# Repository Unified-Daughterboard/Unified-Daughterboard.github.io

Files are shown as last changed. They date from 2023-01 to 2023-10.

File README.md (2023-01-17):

# Unified Daughterboard

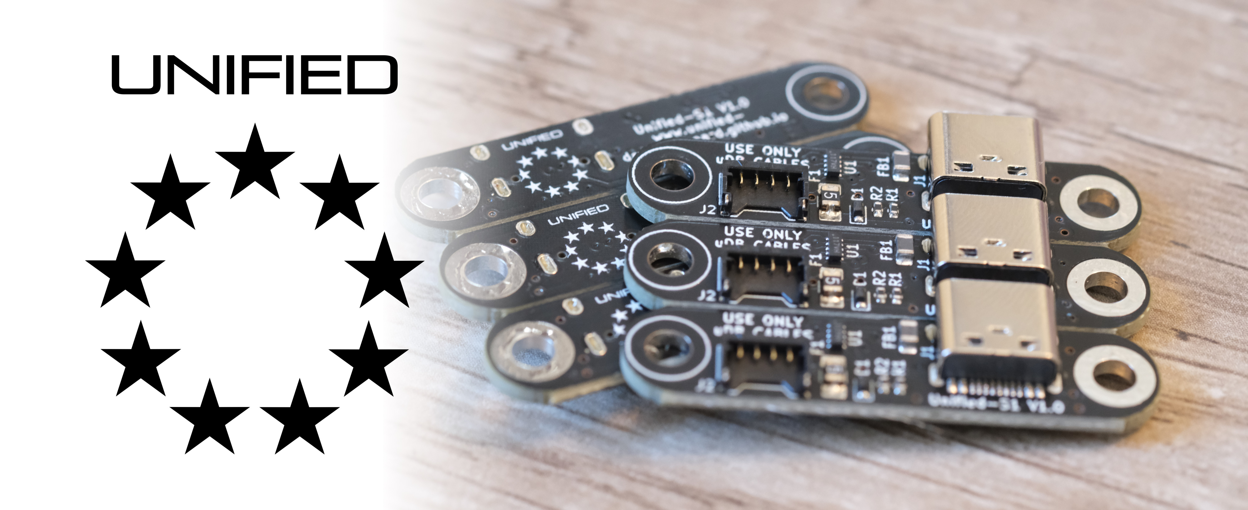
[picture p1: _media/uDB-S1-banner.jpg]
Banner


## Introduction
The Unified Daughterboard Project is an open standard to unify the USB daughterboards used in custom mechanical keyboard projects.  
The USB-to-internal-cable daughterboards allows designers to easily implement electrical protection via a tested proven PCB, and allows users to maintain and repair their keyboards in the future via an open-source standard.  
  
The Unified Daughterboard integrates USB Type C connector and the needed circuitry for USB2.0 operation in a small PCB that can be screwed into a keyboard chassis; this allows for greater case design freedom and simplifies the main circuit board.

## Features
In its latest versions, the daughterboards of this project features ESD protection, overcurrent protection, overvoltage protection, shielding noise decoupling, and single-path grounding to chassis functionality.  
Adittionally, same-letter series (C1, C2, C3, etc.) are backwards compatible, allowing for upgrading daughterboards used in past projects to newer revisions.  

## Project Details
[Roadmap](roadmap.md)  
[Announcements](announcements.md)  

## Resources

[For consumers](info-consumer.md)  
[For case designers](info-designer-case.md)  
[For PCB designers](info-designer-pcb.md)  
[For vendors](info-vendor.md)  
  
[Daughterboard spec and resources](db-spec-list.md)

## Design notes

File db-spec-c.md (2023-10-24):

# C series (C4 and newer) 
Current latest version: C5.0 (Released 2023-10-22)

## Overview

The C series daughterboard is the current most recent revision to the classic square form-factor daughterboard, with its roots in the C1 which was designed to be compatible with Wilba's keyboards.  
The daughterboard features the following:  

* ESD protection, overcurrent protection, overvoltage protection, shielding noise decoupling, and single-path grounding to chassis functionality
* Two variants: The new Molex Pico-EZmate and the classic JST-SH
* 1:1 connector pinout to retain compatibility with existing PCBs
* Same form factor as C1 and C2, allowing for daughterboard upgrades

## Specification

* Overall size: 18 x 16.5 mm
* Screw holes: 14 x 12.5 mm apart.  
* Corner radius: 2 mm
* Hardware: M2 screws
* Connector: Molex Pico-EZmate (781710004)
* PCB layers: 4 (7628 stackup)

## Resources

GitHub: [EZM (Pico-EZmate Variant)](https://github.com/Unified-Daughterboard/UDB-C-EZM ':ignore'), [JSH (JST-SH Variant)](https://github.com/Unified-Daughterboard/UDB-C-JSH ':ignore')  
3D model: [EZM (Pico-EZmate Variant)](/_media/uDB-C4-3D-model.STEP ':ignore'), [JSH (JST-SH Variant)](/_media/uDB-C3-3D-model.STEP ':ignore')  
[Example implementation](/_media/uDB-C4-implementation-example.step ':ignore')  
[Production data](https://github.com/Unified-Daughterboard/UDB-C/tree/main/production ':ignore')  

## Images and Diagrams

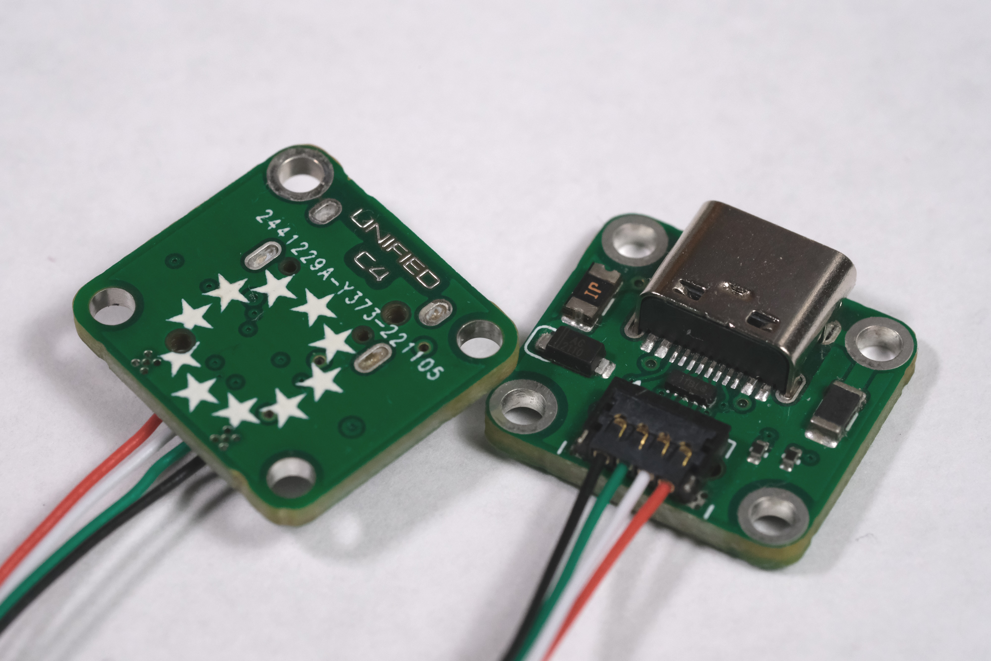
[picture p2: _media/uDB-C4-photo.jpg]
:size=900
  
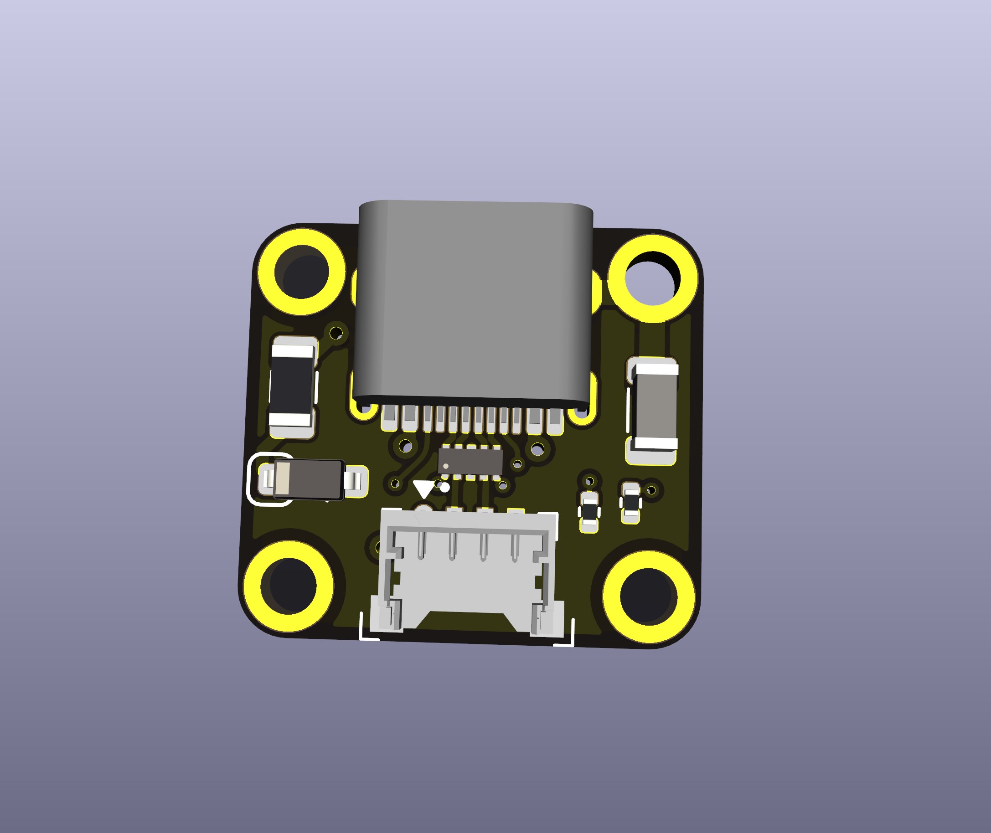
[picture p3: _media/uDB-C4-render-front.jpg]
Render front :size=600
  
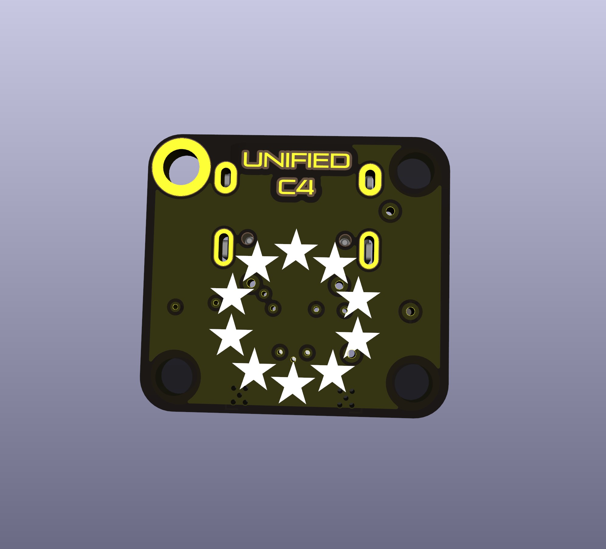
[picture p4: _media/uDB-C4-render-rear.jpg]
Render rear :size=600
  
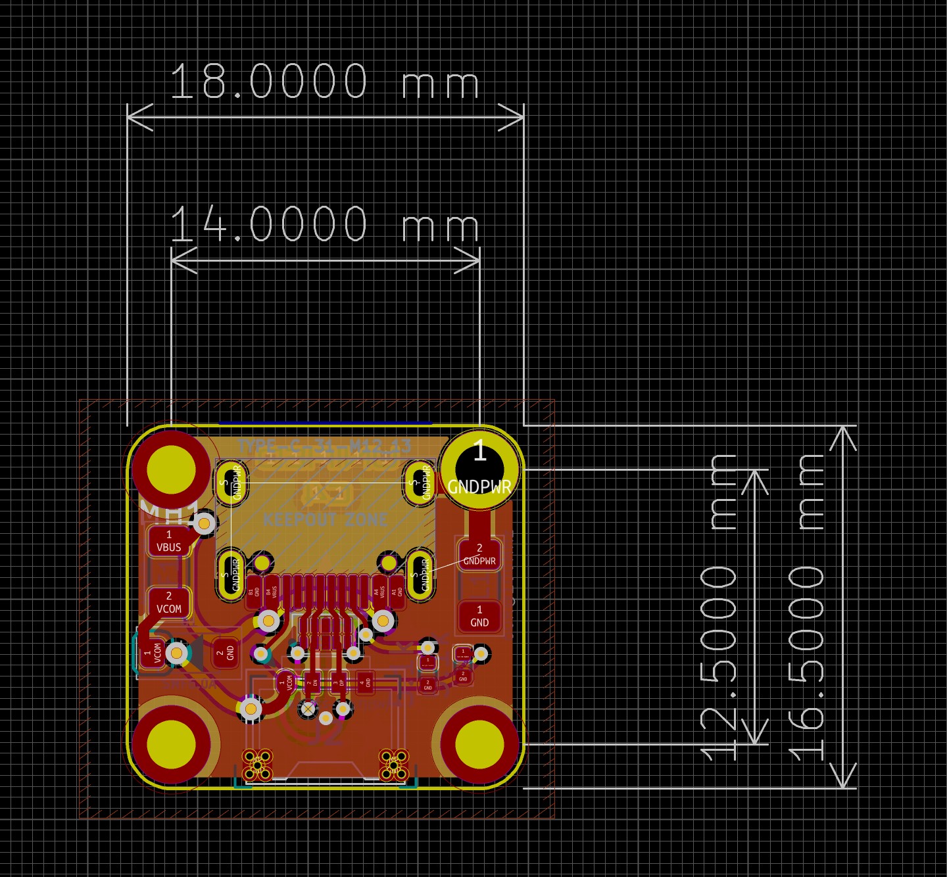
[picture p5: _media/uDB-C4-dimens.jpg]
C :size=600


## Changelog

- 2023-10-22: C5.0 Release
  - Improved ESD handling
  - Added two connector variants
- 2023-03-30: C4.1 Release
  - Updated footprint to S1 series reinforced footprint  
  - Improve USB routing
- 2023-01-18: C4.0 Release
  - Initial release

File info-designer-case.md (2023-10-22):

# Case Designer Info

Information for case designers looking to integrate the Unified Daughterboard into their project.

## Physical dimensions
For dimensions of each daughterboard series, visit [here](db-spec-list.md).  
We recommend importing the provided 3D model for checking dimensional compatibility, as well as checking the example implementations.  
However, please check the important design constraints prior to design.  

## Choosing a daughterboard
We recommend using the newly developed [S series daughterboards](db-spec-s.md) if starting from scratch.  
It is designed to be easier on both the designer and vendor, and has tweaks to reduce possible QC headaches and manufacturing difficulties.  

## Important design constraints
- The PCB should not fully contact the case either on the front or the back - relying on the soldermask to avoid short-circuits against the daughterboard is risky, and has been reported to fail even with no damage to the PCB surface.
  - Instead, air-gap the PCB to the case except for at the screw points. We recommend at least 0.5mm of distance.
- Do not design your keyboard to fit extremely closely against the onboard components - they are subject to change if the circuitry is updated, and the component positions can drift in all directions depending on solder reflow tolerances.
- PCB outline tolerances tend to be around 0.25mm or larger. Please give at least 0.25mm of clearance between the daughterboard design size and surrounding walls.
- Make sure all screws are installed with sufficient thread tap depth.
- Many of the daughterboard's features such as ESD protection rely on a reliable electrical connection from the point of ESD (i.e. the case top half's front bezel) to a select screw point on the daughterboard. Make sure this electrical connection exists through case part contact, screws, and similar if you wish to take advantage of them.

## Cable considerations
A one-to-one 4 pin cable is used to connect the daughterboard to the mainboard - using Pico-EZmate connectors or JST-SH depending on the version.  
  
Consideration should be given to the physical constraints of the cable - for example, make sure it is routed in such a way where it will not be physically damaged during assembly or use.  
A cable too short may interfere with ease of keyboard assembly.  

## Hardware considerations

The C series daughterboards use four M2 screws.  
The S series daughterboards use two M3 screws.  
  
!>The screws should be of regular head type - do not use countersunk screws.  
It is highly recommended to choose a screw with a head diameter lower than 4mm for M2, 6mm for M3. Using larger screws risks the screw reaching over the circuitry-filled areas of the daughterboard.
  
A conductive screw should be used (i.e. uncoated stainless steel) to guarantee conductivity to the case.  
Specifics such as head height and screw length depend on your project's specific constraints.

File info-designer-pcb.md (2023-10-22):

# PCB Designer Info

Information for case designers looking to integrate the Unified Daughterboard into their project.

## Physical dimensions
For dimensions of each daughterboard series, visit [here](db-spec-list.md).  
We recommend importing the provided 3D model for checking dimensional compatibility, as well as checking the example implementations.  
However, please check the important design constraints prior to design.  
  
!>The thickness of the daughterboard *must* be 1.6mm.  
Daughterboards which do not follow this thickness are considered out-of-spec.  

!>4-layer daughterboards (C4 and newer, S1 and newer) *must* be produced on the 7628 stackup.  
4-layer daughterboards not produced to this stackup are considered out-of-spec.  

## Choosing a daughterboard
We recommend using the newly developed [S series daughterboards](db-spec-s.md) if starting from scratch.  
It is designed to be easier on both the designer and vendor, and has tweaks to reduce possible QC headaches and manufacturing difficulties.  

## Cable considerations
A one-to-one 4 pin cable is used to connect the daughterboard to the mainboard.  
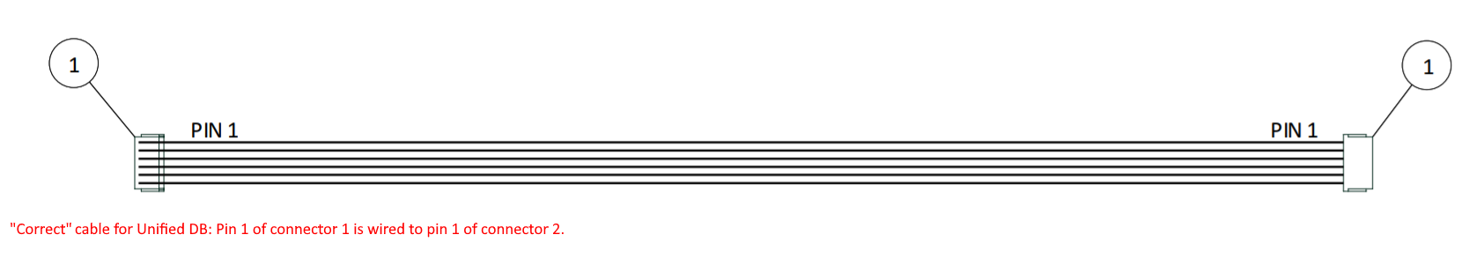
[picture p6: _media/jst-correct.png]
Correct cable diagram :size=900

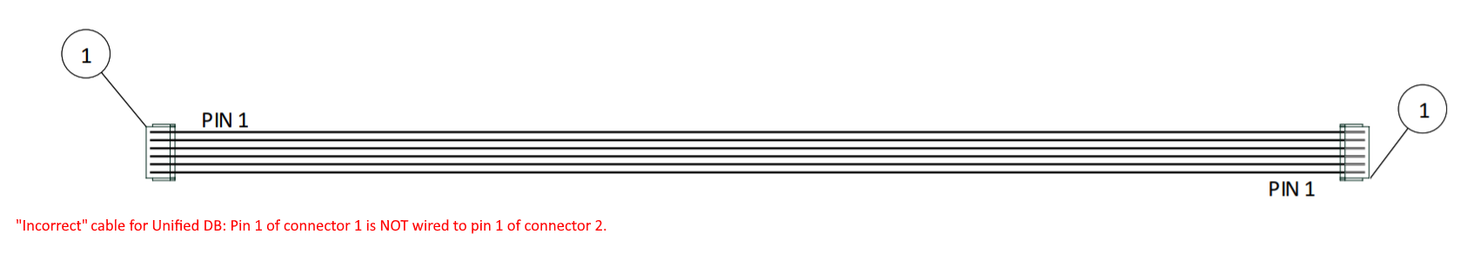
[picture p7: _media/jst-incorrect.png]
Incorrect cable diagram :size=900


The daughterboard uses either Molex Pico-EZmate connectors or JST-SH connectors depending on the choice of daughterboard.  

For testing PCBs, if you do not already have a compatible cable on hand, you can easily construct one using pre-crimped wires and empty housings, simply snapping the wires into the housings in the correct pinout.

| Brand | Component | Part Number | Link |
| --- | --- | --- | ---|
| Molex | Precrimped Wire | 079758101 |[Octopart](https://octopart.com/search?q=0797581010&currency=USD&specs=0)
| Molex | 4-pin Connector | 0781720004 |[Octopart](https://octopart.com/search?q=0781720004&currency=USD&specs=0)
| JST | Precrimped Wire | ACHR-04V-A-S | [Octopart](https://octopart.com/search?q=ACHR-04V-A-S&currency=USD&specs=0)
| JST | 4-pin Connector | ASACHSACH28W152 | [Octopart](https://octopart.com/search?q=ASACHSACH28W152&currency=USD&specs=0)

For mass production, we highly recommend ordering a proper custom batch order, especially since it allows for customizing the cable to the exact needs of the board.  
Please see the [vendor info page](/info-vendor.md) for production diagrams.

## Connector considerations 

The Pico-EZmate connector part number is [Molex 781710004](https://www.digikey.com/en/products/detail/molex/0781710004/2424925). Various connectors are known to be cross-compatible, such as the JST-ACH series [BM04B-ACHSS-A-GAN-TF](https://www.digikey.com/en/products/detail/jst-sales-america-inc/BM04B-ACHSS-A-GAN-TF-LF-SN/1647790)/[BM04B-ACHSS-A-GAN-ETF](https://www.digikey.com/en/products/detail/jst-sales-america-inc/BM04B-ACHSS-A-GAN-ETF-LF-SN/10240659), [this](https://www.lcsc.com/product-detail/Wire-To-Board-Wire-To-Wire-Connector_XFCN-M1201RS-04-BK_C2840019.html), [this](https://www.lcsc.com/product-detail/Wire-To-Board-Wire-To-Wire-Connector_XKB-Connectivity-X1224WRS-04-LPV01_C528030.html), and [this](https://www.lcsc.com/product-detail/Wire-To-Board-Wire-To-Wire-Connector_HCTL-HC-1-2-4PWT_C2997427.html).  
The JST-SH connector part number is [JST SM04B-SRSS-TB(LF)(SN)](https://www.digikey.com/en/products/detail/jst-sales-america-inc/SM04B-SRSS-TB-LF-SN/926875) connector. Various cross-compatible connectors exist for this type.  

Due to the one-to-one nature of the cable, the connector on the mainboard should be of the same pinout as the one used on the daughterboard.  
Please check the KiCad source to verify.

## Important design constraints
- Since all daughterboard variants C3 or newer carry most necessary protections onboard, the main PCB can be left fairly basic in terms of protection.  
  - If you are adding additional protective circuitry on the mainboard, make sure that the total combined schematic along with the uDB is functional and effective.
- As mentioned earlier, make sure you replicate the pinout of the uDB's connector rather than inverting it.
- Avoid placing components directly in front of or near the connector in ways which obstruct the installation of the cable.
- Keep in mind that obstructions such as keyswitch legs may hinder the installation of the cable if the connector is placed in an inconvenient location.

## Daughterboard modifications
Since the source files are available, it is possible to edit the daughterboard design prior to production, such as by adding custom artwork.  
However, please follow these requirements to keep the daughterboard uDB-spec:  
- Please do not modify the circuitry, components, or form factor in any form (i.e. keep edits cosmetic).
- Please make sure the daughterboard is identifiable as a uDB daughterboard by having the text "Unified" onboard in a visible manner.
- Please make sure the daughterboard's series and revision is written onboard in text form in a clear, unambiguous manner (i.e. S1, C4, etc).  
- For versions C5/S2 and newer, please make sure the daughterboard's connector type identifier (EZM or JSH) is marked on the board in a clear, unambiguous manner.

This helps keep your keyboard project maintainable and sustainable into the future by letting users identify the daughterboard during replacement.

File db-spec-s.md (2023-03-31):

# S series (S1 and newer)
Current latest version: S1.1  (Released 2023-03-30)

## Overview

The S variant daughterboard was developed as an entirely new form factor from the older C3 version based on real-world production usage and designer input.

- "Wide and narrow" 40mm wide x 9mm deep x 1.6mm thick form factor
    - Avoids obstacles such as weights commonly found in custom keyboards
    - Mountable both right-side-up and upside-down
- 2 x M3 mounting points 
    - Fewer large screw taps reduce thread defect issues and assembly effort
- Easy and inexpensive to source via JLCPCB or similar
- Large DB corner radii which allow keyboard cases to be milled at a large inner radius
- ESD protection, overcurrent protection, overvoltage protection, shielding noise decoupling, and single-path grounding to chassis functionality
- New Molex Pico-EZmate Connector, replacing the JST-SH on previous versions
- 1:1 connector pinout to retain compatibility with existing PCBs

## Specification
* Overall size: 40 x 9 mm
* Screw holes: 33 mm apart
* Hardware: 2x M3 screws
* Connector: Molex Pico-EZmate (781710004)
* PCB layers: 4 (7628 stackup)

## Resources

[GitHub](https://github.com/Unified-Daughterboard/UDB-S ':ignore')  
[3D model](/_media/uDB-S1-3D-model.STEP ':ignore')  
[Example implementation, right-side up](/_media/uDB-S1-implementation-example.step ':ignore')  
[Example implementation, upside-down](/_media/uDB-S1-implementation-example-reverse.step ':ignore')  
[Production data](https://github.com/Unified-Daughterboard/UDB-S/tree/main/production ':ignore')  

## Images and Diagrams

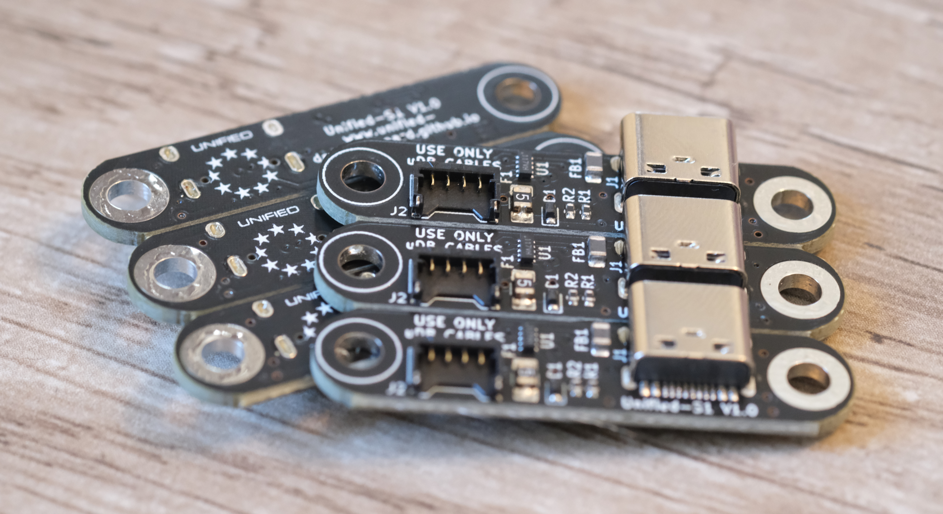
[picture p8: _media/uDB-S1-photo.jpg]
:size=900

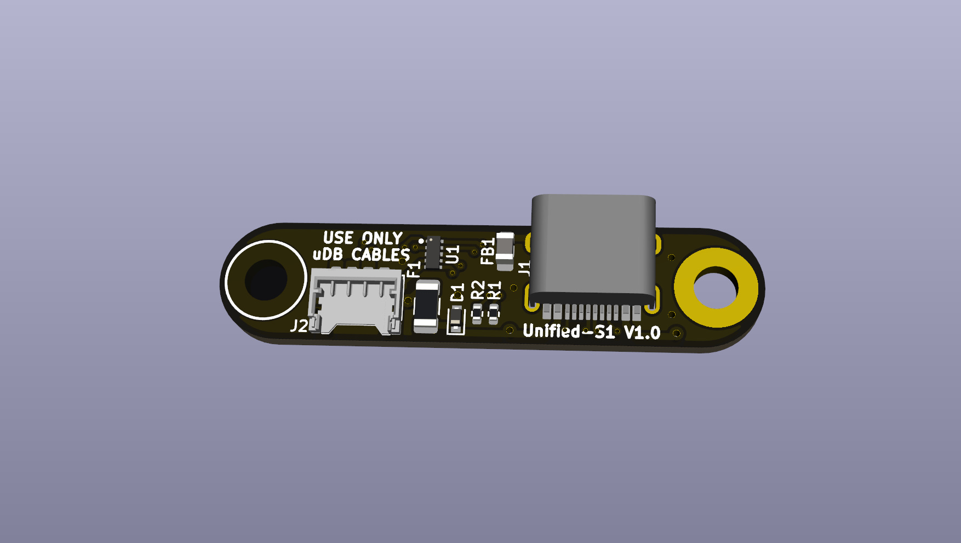
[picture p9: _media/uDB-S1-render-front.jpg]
Render front :size=900

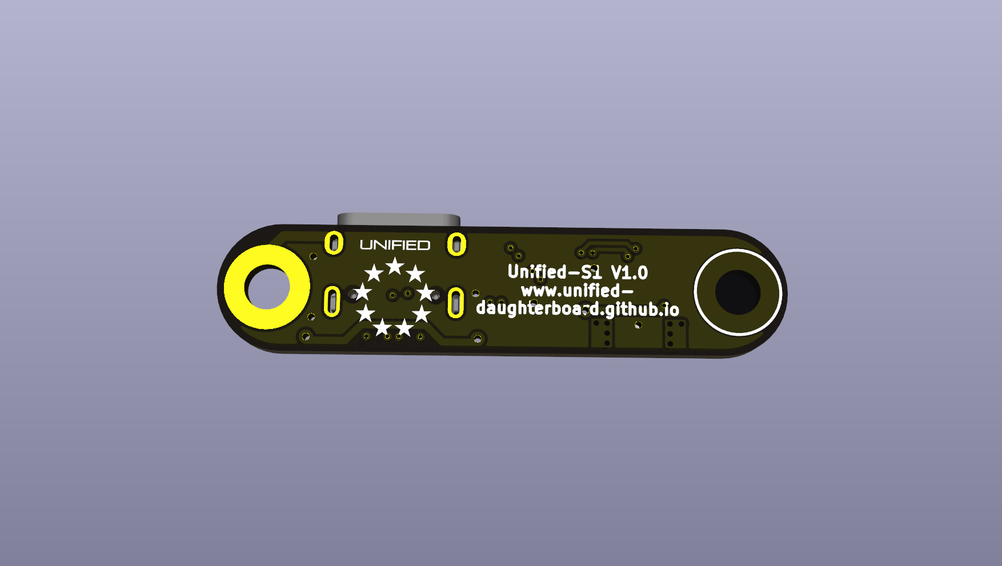
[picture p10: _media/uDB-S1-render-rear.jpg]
Render rear :size=900

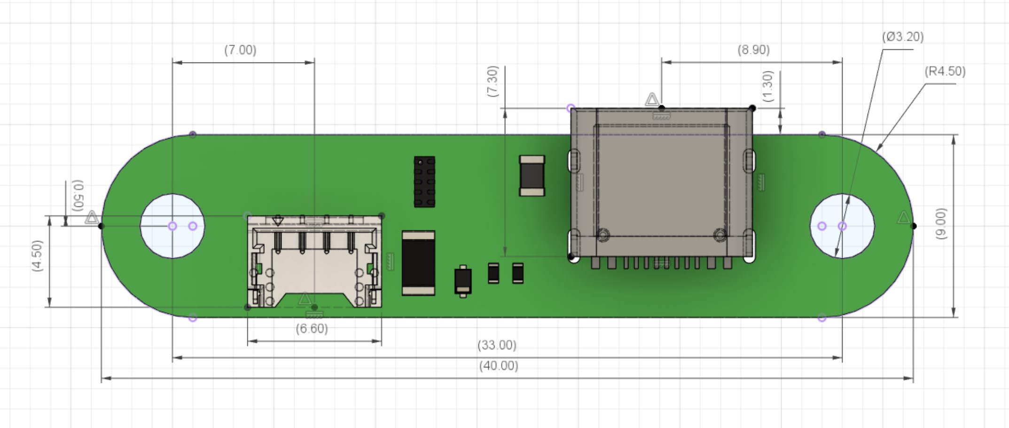
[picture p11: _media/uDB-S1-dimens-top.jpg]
S series, top :size=900

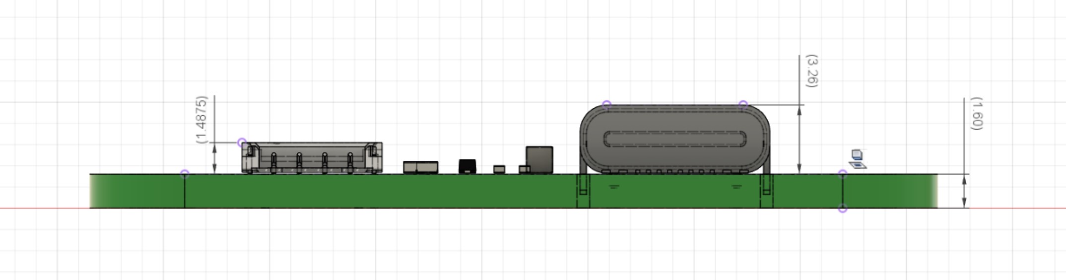
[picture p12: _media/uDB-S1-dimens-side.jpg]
S series, side :size=900


## Changelog

- 2023-03-30: S1.1 Release
  - Improve USB routing
- 2023-01-18: S1.0 Release
  - Initial release

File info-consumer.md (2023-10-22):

# Consumer Info

If you're a keyboard enthusiast and are looking for details on maintenance or repair, you're in the right place.

## Using USB-spec cables
A proper USB cable has an outer electrical shield, which keeps operation reliable and assists in handling ESD (static shocks).  
The Unified Daughterboard's protection circuitry is designed with the expectation that this shield exists and is functional - without it, the ESD protection features may be severely degraded or nonexistent.  

!> There have been countless reports of people destroying their keyboards with a single static zap when using expensive "boutique" cables with a missing or incorrectly wired shield - to make sure that the uDB can protect your keyboard, **please make sure that your cable meets USB spec**.  

## Buying replacement daughterboards
If a daughterboard breaks, it can be replaced with any of the daughterboards of the same series.  
It is not recommended to go backwards in numbering; i.e. do not downgrade from a C3 to C1 if the board came with a C3. If you do, you will likely lose certain features such as advanced ESD protection.  

?> Daughterboards not of the same series are not interchangeable (i.e. a S1 daughterboard will not fit in a C3 daughterboard cutout or vice versa).  
Double-check the [daughterboard type](db-spec-list.md) before purchase.  

## Buying replacement cables
Always use cables with both the correct connector and correct wiring. Incorrect cables may cause permanent damage to your keyboard.  
When in doubt, ask the vendor which you purchased your keyboard from, or buy a replacement cable clearly notated to be compatible with the specific Unified Daughterboard series in use in your keyboard.  

!>Even if the cable can *physically* connect due to using the correct connector, it might not be *electrically* compatible - the order the pins are wired in may differ from spec.  
Connecting a cable of incorrect pin order may cause permanent electrical damage to the main PCB - do not substitute unidentified cables or cables from non-uDB keyboards.

### Molex or JST?
- If your daughterboard is versions C1 to C3, you have the JST-SH connector.  
- If your daughterboard is version C4 or S1, you have the Molex Pico-EZmate connector.  
- If your daughterboard is version C5, S2, or newer, look for the label on the back of the PCB.
  - If the label contains "JSH", you have the JST-SH connector.
  - If the label contains "EZM", you have the Molez Pico-EZmate connector.

For a quick sanity check: If your cable "slides in" to the connector horizontally, you are looking for a JST-SH cable; if your cable "snaps in" perpendicularly into the PCB, you are looking for a Pico-EZmate cable.  
When in doubt, ask the vendor which you purchased your keyboard from.

### Pinout
The Unified Daughterboard series uses a "one-to-one" cable, i.e. pin 1 of connector 1 corresponds to pin 1 of connector 2.  
See the example diagrams below for more info - specifically take a look at the connectors.  
Correct cable diagram :size=900
Incorrect cable diagram :size=900

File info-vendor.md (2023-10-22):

# Vendor Info

Information for vendors and manufacturers looking to arrange production of a Unified Daughterboard.

## USB-Spec Cables
A proper USB cable has an outer electrical shield, which keeps operation reliable and assists in handling ESD (static shocks).  
The Unified Daughterboard's protection circuitry is designed with the expectation that this shield exists and is functional - without it, the ESD protection features may be severely degraded or nonexistent.  

!>There have been numerous reports of people destroying their keyboards with static shocks when using custom cables with a missing or incorrectly wired shield.

To avoid damages in replacements, **we highly recommend that vendors do the following**:
  
* Recommend to customers that keyboards (regardless of uDB or not) are only used with a cable which follows USB spec.  
* Only sell or recommend use with USB cables with a properly implemented shield.  

For further information such as the USB foundation cable spec when ordering cables from manufacturers, please see the [Notices for USB Cable Makers](info-cable-maker.md) page.

## Production Spec
!>The thickness of the daughterboard *must* be 1.6mm.  
Daughterboards which do not follow this thickness are considered out-of-spec.  

!>4-layer daughterboards (C4 and newer, S1 and newer) *must* be produced on the 7628 stackup.  
4-layer daughterboards not produced to this stackup are considered out-of-spec.  

## PCB Connector Part

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

## Cable Spec

A one-to-one 4 pin cable is used to connect the daughterboard to the mainboard.  
Make sure the cable is one-to-one - an incorrect inverted cable can cause irreversible damage to the mainboard.
Correct cable diagram :size=900
Incorrect cable diagram :size=900

### Prototype Cables

For testing PCBs, if you do not already have a compatible cable on hand, you can easily construct one using pre-crimped wires and empty housings, simply snapping the wires into the housings in the correct pinout.

| Brand | Component | Part Number | Link |
| --- | --- | --- | ---|
| Molex | Precrimped Wire | 079758101 |[Octopart](https://octopart.com/search?q=0797581010&currency=USD&specs=0)
| Molex | 4-pin Connector | 0781720004 |[Octopart](https://octopart.com/search?q=0781720004&currency=USD&specs=0)
| JST | Precrimped Wire | ACHR-04V-A-S | [Octopart](https://octopart.com/search?q=ACHR-04V-A-S&currency=USD&specs=0)
| JST | 4-pin Connector | ASACHSACH28W152 | [Octopart](https://octopart.com/search?q=ASACHSACH28W152&currency=USD&specs=0)

### Production Cables

For mass production, we highly recommend ordering a proper custom batch order (i.e. via [Alibaba listings](https://www.alibaba.com/product-detail/Customized-Molex-EZmate-to-Molex-EZmate_1600697379284.html) or similar), especially since it allows for customizing the cable to the exact needs of the board.  
The following manufacturing diagrams provided by Hiney may aid in the process.
  
#### Typical Pico-EZmate cable, without heatshrink  
This yields the lowest overall cable profile, but the strands are free to separate.  
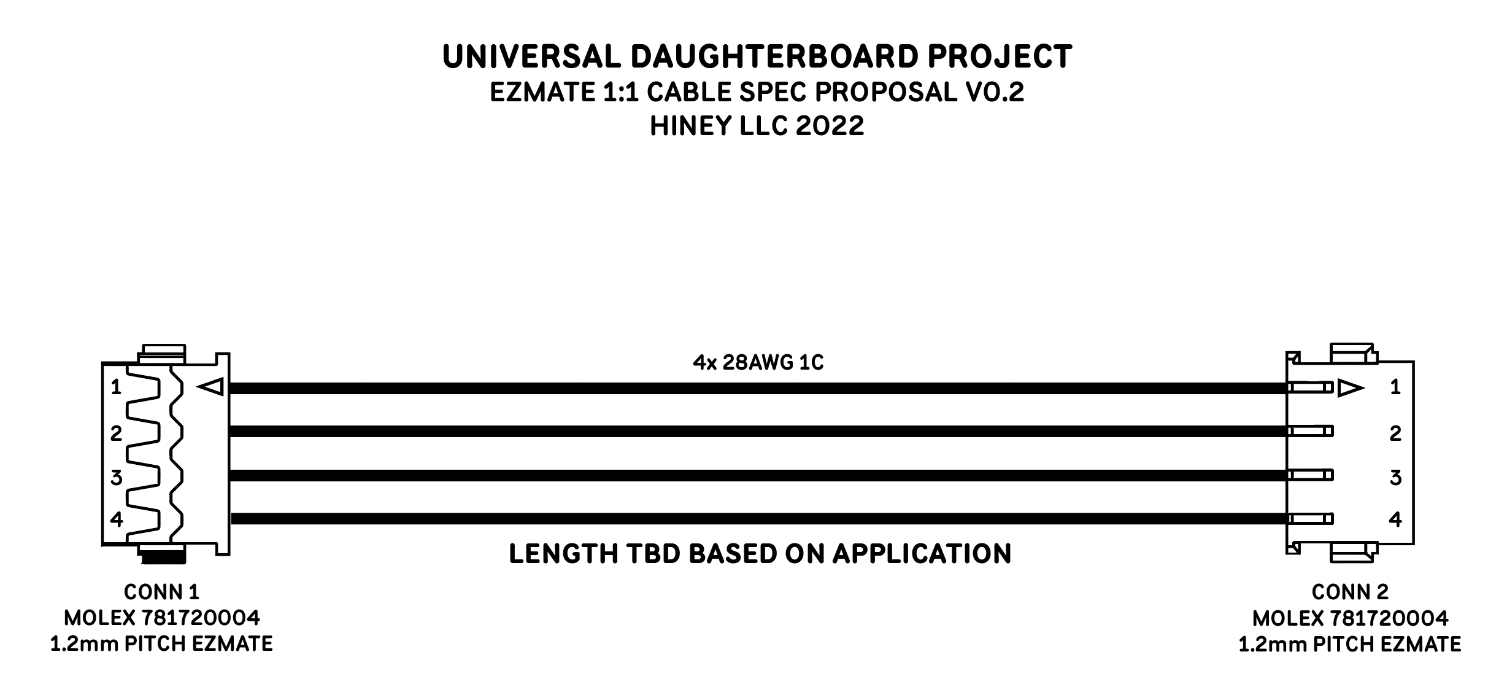
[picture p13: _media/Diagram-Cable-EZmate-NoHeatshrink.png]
Diagram :size=700


#### Typical Pico-EZmate cable, with heatshrink  
The heatshrink tube bundles the wires together to a certain extent.  
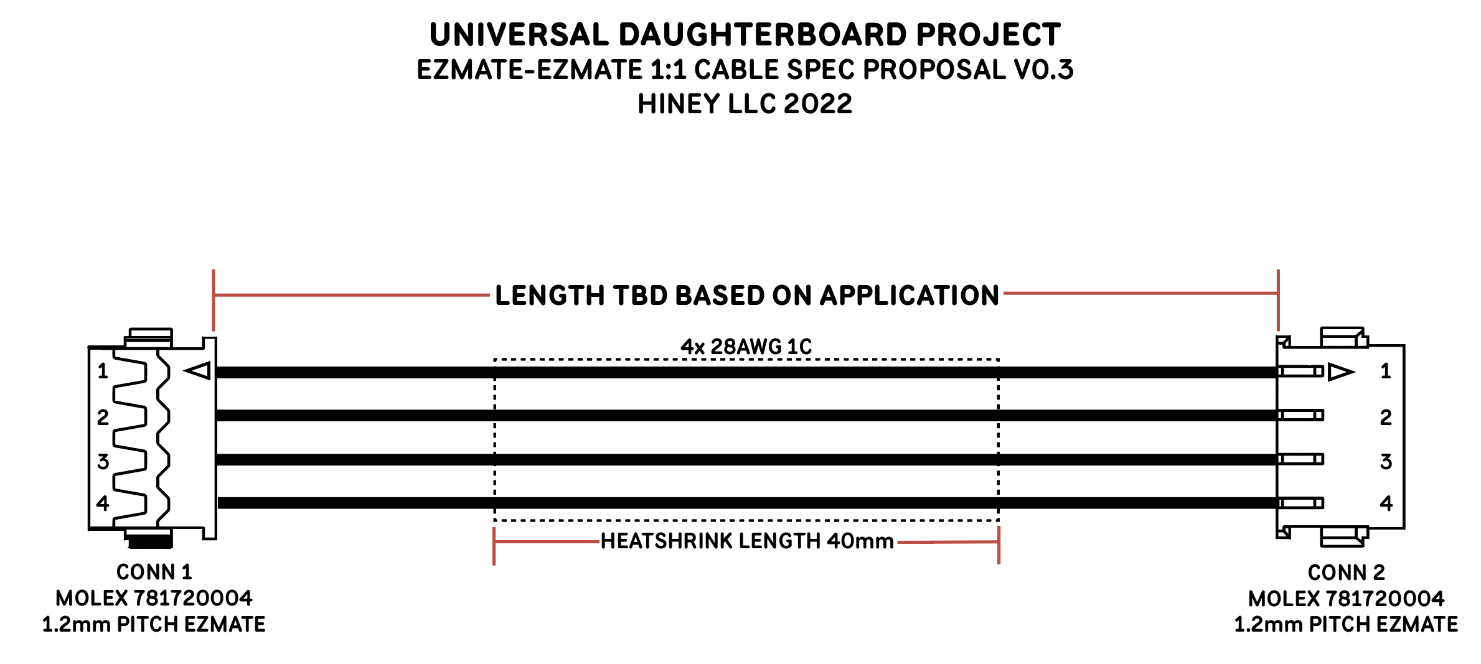
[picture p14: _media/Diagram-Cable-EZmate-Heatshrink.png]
Diagram :size=700


#### Atypical Pico-EZmate to JST-SH adapter cable, without heatshrink  
This is a unique EZmate to JST-SH cable used in situations where one end or the other must be the old JST-SH type.  
This can be used to run newer (C4+, S1+) daughterboards with older legacy PCBs which use the JST connector, or vice versa.  
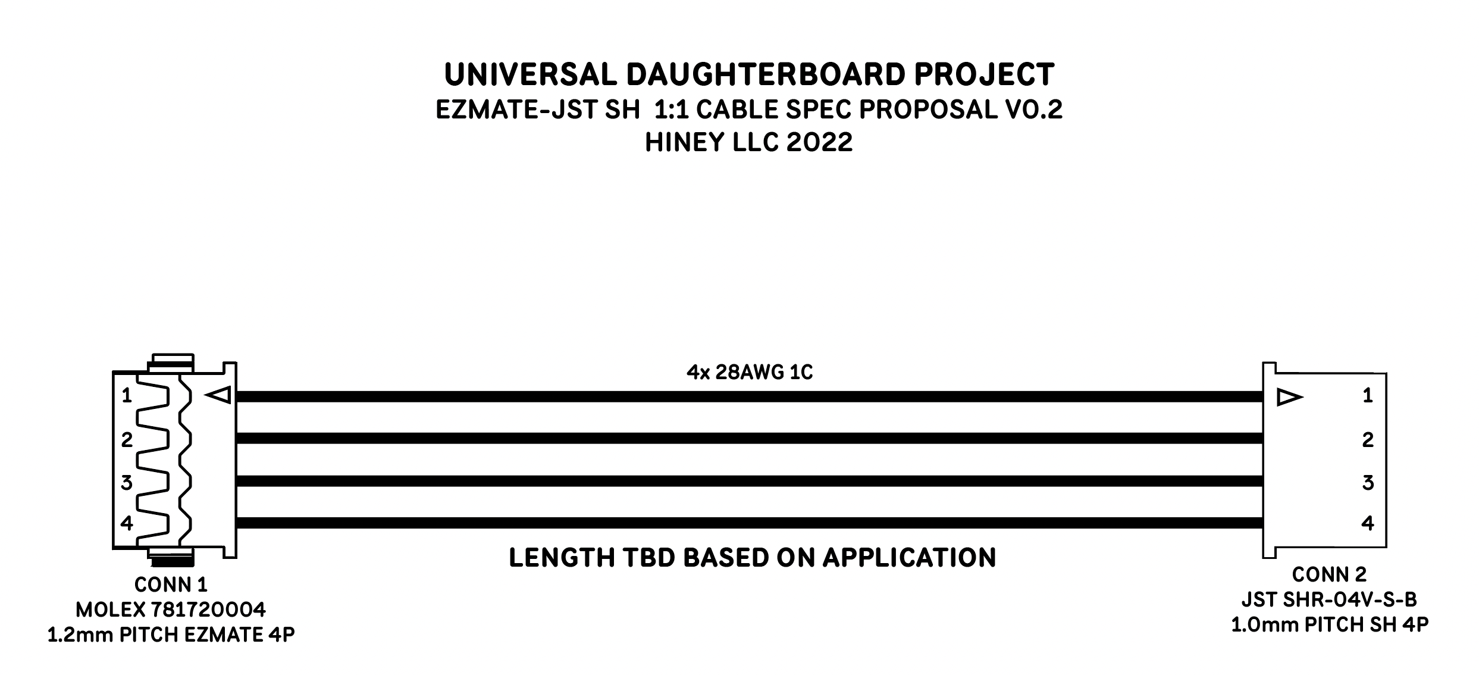
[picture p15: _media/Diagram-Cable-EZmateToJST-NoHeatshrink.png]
Diagram :size=700


#### Atypical Pico-EZmate to JST-SH cable, with heatshrink  
This is a unique EZmate to JST-SH cable used in situations where one end or the other must be the old JST-SH type.  
This can be used to run newer (C4+, S1+) daughterboards with older legacy PCBs which use the JST connector, or vice versa.  
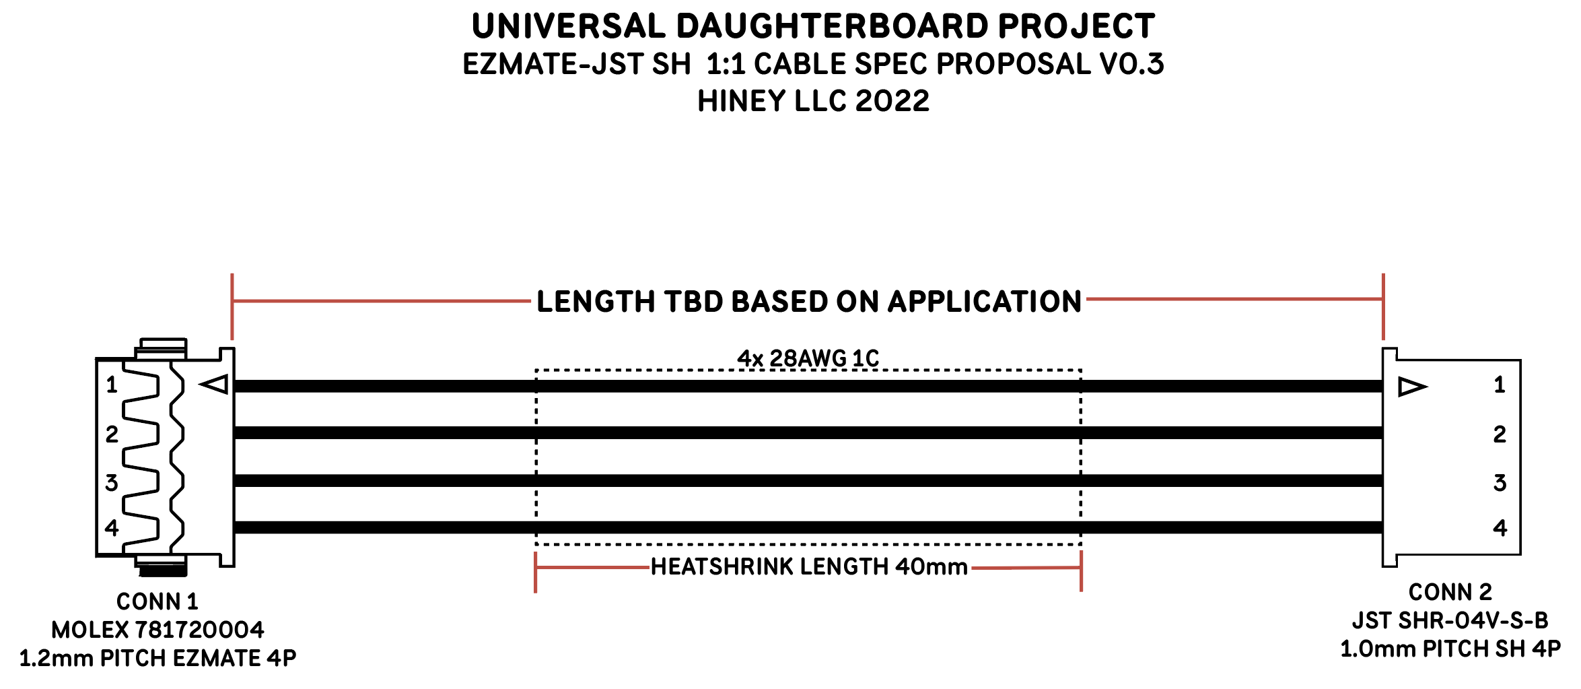
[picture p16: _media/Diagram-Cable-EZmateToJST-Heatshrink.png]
Diagram :size=700


## Daughterboard modifications
Since the source files are available, it is possible to edit the daughterboard design prior to production, such as by adding custom artwork.  
However, please follow these requirements to keep the daughterboard uDB-spec:  
- Please do not modify the circuitry, components, or form factor in any form (i.e. keep edits cosmetic).
- Please make sure the daughterboard is identifiable as a uDB daughterboard by having the text "Unified" onboard in a visible manner.
- Please make sure the daughterboard's series and revision is written onboard in text form in a clear, unambiguous manner (i.e. S1, C4, etc).  
- For versions C5/S2 and newer, please make sure the daughterboard's connector type identifier (EZM or JSH) is marked on the board in a clear, unambiguous manner.

This helps keep your keyboard project maintainable and sustainable into the future by letting users identify the daughterboard during replacement.

## Hardware Spec

The C series daughterboards use four M2 screws.  
The S series daughterboards use two M3 screws.  
  
!>The screws should be of regular head type - do not use countersunk screws.  
It is highly recommended to choose a screw with a head diameter smaller than 4mm for M2, 6mm for M3. Using larger screws risks the screw reaching over the circuitry-filled areas of the daughterboard.
  
A conductive screw should be used (i.e. uncoated stainless steel) to guarantee conductivity to the case.  
Specifics such as head height and screw length should be discussed with the case designer.

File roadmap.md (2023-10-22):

# Roadmap

## 2023/03/30 - uDB C5 Release
* Announcement post - [2023-10-22: uDB C5 Release](announcements/announcement-20231022.md)
* Successor to C4.1
* Improved ESD handling
* Added connector variants

## 2023/03/30 - uDB C4.1 Release
* Successor to C4
* Replaces C4's Pico-EZmate footprint with a reinforced variant from S1
* Tweaked signal routing for USB high-speed reliability  

## 2023/03/30 - uDB S1.1 Release
* Successor to S1
* Tweaked signal routing for USB high-speed reliability  

## 2023/01/18 - uDB S1 Release
* Announcement post - [2022-01-18: S1 and C4 Release](announcements/announcement-20230118.md)
* New form factor
  * Narrow and wide shape which fits with less conflict on custom keyboards
  * Larger corner radii for easier case manufacturing
  * Two M3 screws which reduce logistics effort and thread tap QC reject rate
* New connector: Molex Pico-EZmate series
  * Improved physical robustness and resistance to shearing
  * Durable against pin damage
  * Lower profile; reduced constraint on case-side design

## 2023/01/18 - uDB C4 Release
* Announcement post - [2022-01-18: S1 and C4 Release](announcements/announcement-20230118.md)
* Successor to C3
* New connector: Molex Pico-EZmate series
  * Improved physical robustness and resistance to shearing
  * Durable against pin damage
  * Lower profile; reduced constraint on case-side design

## 2020/05/03 - uDB C3 Release
* C1 updated with protection circuitry

## 2019/05/20 - uDB C1 Release
* Initial release

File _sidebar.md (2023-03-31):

* [Home](/#unified-daughterboard)
* [Roadmap](roadmap.md)
* [Announcements](announcements.md)
*
<hr style="border-color: rgba(0, 0, 0, .07);">
* [uDB Spec and Resources](db-spec-list.md)
  * [S Series](db-spec-s.md)
  * [C Series](db-spec-c.md)
  * [Legacy C Series](db-spec-c-legacy.md)  
*
<hr style="border-color: rgba(0, 0, 0, .07);">
* [Consumer Info](info-consumer.md)
* [Case Designer Info](info-designer-case.md)
* [PCB Designer Info](info-designer-pcb.md)
* [Vendor Info](info-vendor.md)
* [Notices for USB Cable Makers](info-cable-maker.md)
*

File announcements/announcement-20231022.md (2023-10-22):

# 2023-10-22 - Unified Daughterboard C5 Release
## ESD handling revisited, connector choices

Today we're launching the C5 Unified Daughterboard revision, with major changes to ESD handling and internal connector choices.

The tl;dr changes list are as follows:
- Improved ESD handling under conditions with imperfect USB cables.
- Offering both JST-SH and Molex Pico-EZmate versions, denoted with suffixes -JSH and -PEM respectively.

*This is a rather important announcement - we highly recommend that all vendors and designers give this a thorough read.*

## ESD Improvements

Up until the previous uDB versions, ESD had always been handled with the expectation that the USB cable is built to [USB specification](https://www.usb.org/sites/default/files/USB%20Type-C%20Spec%20R2.0%20-%20August%202019.pdf). Within the requirements for cable assemblies, some of the most critical are the requirements regarding the shield:

Specifically, the USB C cable spec calls out the following needs:
- A full internal mesh metal shield with a drain wire exists, continuous from end to end and separate from the ground conductor.
- The shield is connected to the outer barrel of the USB-C connector within the connector itself.
- The shield is also connected to the ground conductor within the connector itself.

With the spec followed, the previous Unified Daughterboard versions perform just fine, mitigating any static shocks to the case by channeling them to the USB connector shield.
A ferrite bead kept the shield loosely tied to the signal ground, preventing the cable shield from behaving unpredictably.

### *The reality of imperfect cables*

With the carefully chosen and implemented circuit, we had many headaches and discussions as reports continued to come in of users damaging their keyboards with static shocks; in our experience.  
After much investigation, we pinpointed the issue down to both boutique custom USB cables and cost-cutting budget cables, both of which would often implement the USB shield and wiring incorrectly.  
While in an ideal world we could say "don't use out-of-spec cables", custom cables play a strong role in the use of custom keyboards, and USB spec-ness is difficult to check without disassembling the cable.  

To solve the issue once and for all, we reached out to a highly regarded professional in the field of electrical engineering, who partered up with Gondolindrim of the Unified Daughterboard team (also an experienced ESD and EMI specialist) for their advice on how to handle the conflicting goals - handling things as properly as possible when an in-spec cable is used while also protecting the keyboard when an out-of-spec cable is in place.
With their feedback, we replaced the ESD handling circuit with one which should perform adequately both with in-spec and out-of-spec cables - the USB connector shield is tied directly to signal ground through a contained ground plane, allowing the static shocks to be diverted to the USB cable ground if the shield is missing or miswired while avoiding issues with shield-induced currents interfering with delicate components of the keyboard PCB itself.

As an added bonus, there is one less component on the PCB now - it might save a few dollars over larger quantity orders.

### *Is there a downside?*

The trouble with supporting both shielding and grounding is that the daughterboard simultaneously handles two contradictory purposes: blocking high frequency EMI from reaching the connector at the same time as offering a low-impedance path to that same connector to account for ESD events. There are multiple solutions both in literature and online, each of which with its downsides.

The previous uDB versions - C3 and C4 - dealt with shielding in a natural way: a ferrite bead was connected from shield to ground. At high speeds this bead blocks high-speed EMI signals, and at low frequencies it presents itself as a low impedance.  

However, this strategy fails when the USB cables used are not properly grounded and shielded, sincee it relies on a solid connection of the USB shield to ground.  
Because of this, with the C5 revision, we decided to simply connect the USB shield chassis to the signal ground. There are two challenges associated with this approach.  

- Upon connecting the keyboard to the computer, the downstream ground (of the keyboard) and the upstream ground (of the computer) are suddenly shorted together and can cause impulsive currents from the voltage difference; those are generally called ground loops. However, most modern USB upstream ports are prepared to deal with this phenomenon.
- Noise picked up on the USB cable shield can cause unpredictable current within ground on the uDB itself, which can cause issues with ground noise and EMI.

In practice, the uDB has been designed carefully to mitigate these downsides: a contained ground area for the USB connector ground is connected to the keyboard PCB ground signal through a single narrow point of connection via a technique called "ground islanding". This is done to prevent the unpredictable ground loop currents and the noisy EMI from reaching the keyboard circuitry as much as possible, containing these currents in the region close to the USB cable and connector.

Adittionally, the C5 daughterboard has an electrically active screw hole which grounds the keyboard chassis if it is metallic. This ensures that the keyboard chassis does its part together with the ESD protection circuitry of the uDB to handle static shocks.

## Connector Choices

In the previous S1 and C4 versions, we launched the first Unified Daughterboards with the Molex Pico-EZmate connectors - offering higher current handling, more robust terminals, and a compact form factor.
While we tested these connectors rigorously before the launch of the daughterboards, we've heard back from quite a few users and designers about issues that have shown up in real-world deployment:
- Connectors loosening until they cannot connect physically
- Connectors receiving damage during cable insertion or removal
- Cable breaking at the connectors

One of the primary goals of the Unified Daughterboard project is reliability and practicality under real-world use - we researched into various solutions to this problem.

In the end, we couldn't find a perfect solution - leaving everything EZmate would do nothing to resolve the newly reported issues, and fully reverting to JST-SH used on versions C3 and earlier would leave people who invested into the EZmate ecosystem stranded - not to mention that JST-SH has its own share of physical robustness issues.  
While we understand that this will cause confusion especially for the users, until we can collect statistics, test further, and potentially search for alternative connectors, we will be releasing both a Pico-EZmate and JST-SH version of the new S2 and C5 daughterboards, denoted by the suffixes -PEM and -JSH respectively.  

## Looking Forward

As much as we would like to unify the connector used on the Unified daughterboard series down to one, due to the issues described above, we currently do not have a decision on whether we will unify them together - whether by dropping support for one or the other or by looking for an entirely different connector that resolves all issues.  
For the time being, both variants will be supported equally.  
  
In the future, we plan to update the S series daughterboards with the same improvements applied to the C series.

## Resources 
The new C5 files are available on GitHub, and are linked to from the [C-series page](https://unified-daughterboard.github.io/#/db-spec-c).

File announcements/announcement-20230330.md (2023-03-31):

# 2023-03-30 - S1.1 and C4.1 Release

## Overview

As an incremental upgrade to the S1 and C4 series launched a few months ago, the S1.1 and C4.1 revisions have been released.  
Changes are minor - they are designed as drop-in upgrades to existing boards where S1 and C4 are used, and are backwards-compatible.  
Huge credits to Gondolindrim for calculating and implementing the updated USB routing (more on this below).  

## C4.1 Changes
- The footprint for the Molex Pico-EZmate connector has been swapped to the one used on the S1, improving the physical reinforcement on the connector while also mitigating potential issues with solder being "vacuumed out" of the pad through vias during assembly.  
- Routing has been updated to be in line with USB high-speed standards, offering improved signal reliability under high speed communications.  

## S1.1 Changes
- Routing has been updated to be in line with USB high-speed tier standards, offering improved signal reliability under high speed communications.  

## Release Data
The data for each daughterboard has been reflected in the GitHub repositories and project pages on this site.

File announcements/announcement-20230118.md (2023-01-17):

# 2023-01-18 - S1 and C4 Release

## Background

In 2019, the first C1 variant of the Unified Daughterboard was released in an effort to create a new standard for custom keyboard daughterboards. It was based heavily on the work that Wilba did on his RAMA and Keycult daughterboards, and has currently become the de-facto standard in many keyboards. Currently it has been through a few iterations, and is now on its third and longest running revision - the C3.

But recently, we noticed the proliferation of new daughterboard designs. While the Unified Daughterboard C3 form factor is great for many reasons, it does have some limitations. Because the current daughterboard is close to square-shaped, occasionally the DB is too long depth-wise to fit into a design.

The alternative daughterboards that have cropped up often share a few characteristics to help address this issue - primarily, they are wider than they were tall, and not as deep as the Unified Daughterboard. But we also saw a few problems - mainly, not every daughterboard offered the same level of electrical protection as the C3 daughterboard.

## The S1 Slimline Daughterboard

In an effort to do for this form factor what the Unified Daughterboard C3 did for a different form factor, we're pleased to introduce the new [S1 Slimline Daughterboard](https://github.com/Unified-Daughterboard/UDB-S)!

S1 Slimline Daughterboard

The Slimline Daughterboard has the following features:

- 40mm wide x 9mm deep x 1.6mm thick form factor
- 2 x M3 mounting points 
    - Fewer large screw taps reduce thread defect issues and assembly effort
- Easy and inexpensive to source via JLCPCB or similar
- Mountable both right-side-up and upside-down
- Large DB corner radii so keyboard cases can be milled at a large inner radius
- ESD protection, overcurrent protection, overvoltage protection, shielding noise decoupling, and single-path grounding to chassis functionality
- New Molex Pico-EZmate Connector (781710004), replacing the JST-SH on previous versions
- 1:1 connector pinout to retain compatibility with existing PCBs

## Connector Choice

One major change between the C3 daughterboard and S1 is the choice of connector. We've decided to change to Molex Pico-EZmate.

Almost every daughterboard to date has used JST-SH connectors as their board-to-board connector, and for good reason - JST-SH connector parts are easily available, cheap, and relatively easy to use. Any replacement had to check these boxes.

But over the years, we've also found some downsides of using JST-SH:

- The JST-SH connector is taller than a hotswap socket. This added design constraints case-side, such as necessitating extra cutouts for connector clearance.
- The tall JST connectors created an extra failure point on shipping. The worst experience is opening a PCB just to find the JST connector has broken off, and this could happen despite best efforts at packaging.
- The thin, fragile pins inside the JST connector are easily bent if the cable was inserted incorrectly with too much force or at an angle.
- The cable is installed parallel to the PCB, creating shear-forces and risking irriversible damage to the connector and/or PCB.

So we searched for alternatives. The Molex Pico-EZmate connectors were already in use by some folks in the keyboard community, primarily on the Fly Daughterboard developed by ToastyStoemp. 

To connect a cable with Pico-EZmate, instead of pushing a cable parallel to the PCB, the cable is pressed down into to the PCB. This perpendicular direction of force aids in preventing shearing pads during insertion, and also allows the connector to detach itself rather than shear itself off the PCB if the cable is pulled unexpectedly (for example, if the keyboard is disassembled while forgetting that the cable connection exists).

Because the Pico-EZmate connector has a lower profile than a hotswap socket, the connector positioning on the PCB becomes less critical. With JST-SH, if a case isn't deep enough to fit a connector, a specific channel has to be cut and the PCB must be designed to match that. This also means if a keyboard's proprietary PCB fails and there are no extra PCBs available, that entire keyboard is effectively out of commission. With this change, any PCB using the Pico-EZmate-connector can be used as a replacement even if the connector position does not match the original.

We contacted designers that already had prototypes in hand or were planning on using the Pico-EZmate connector, and we only heard positive feedback. Given this feedback and our own personal experiences in testing the connector - we decided to make the change.

The Pico-EZmate connectors are available at low-cost, and are easier to use than JST connectors for the end user. There are a [few](https://www.lcsc.com/product-detail/Wire-To-Board-Wire-To-Wire-Connector_XFCN-M1201RS-04-BK_C2840019.html) [different](https://www.lcsc.com/product-detail/Wire-To-Board-Wire-To-Wire-Connector_XKB-Connectivity-X1224WRS-04-LPV01_C528030.html) [options](https://www.lcsc.com/product-detail/Wire-To-Board-Wire-To-Wire-Connector_HCTL-HC-1-2-4PWT_C2997427.html) available at LCSC and for assembly at JLCPCB.

## Cables

The main downside we identified for Pico-EZmate is cable availablity. Most prebuilt cables available off-the-shelf are not 1:1, and they are harder to find than JST-SH cables (with JST-SH, [qwiic cables](https://www.sparkfun.com/products/15081) shared a pinout).

However, we have identified multiple solutions.

Many keyboard vendors have committed to stocking cables at a reasonable price. And we've also made technical drawings available from hineybush for anyone who wants to source their own. We believe this will be the easiest way to source cables. The Fly DB that GEON offers also uses the same cables.

In addition to this, both Molex and JST sell cable parts that can be easily put together to create cables. Each brand sells connectors and pre-crimped single wires that are compatible with Molex Pico-EZmate. Building a full cable is as easy as inserting the pre-crimped wires into the connectors in the proper direction. 

| Brand | Component | Part Number | Link |
| --- | --- | --- | ---|
| Molex | Precrimped Wire | 079758101 |[Octopart](https://octopart.com/search?q=0797581010&currency=USD&specs=0)
| Molex | 4-pin Connector | 0781720004 |[Octopart](https://octopart.com/search?q=0781720004&currency=USD&specs=0)
| JST | Precrimped Wire | ACHR-04V-A-S | [Octopart](https://octopart.com/search?q=ACHR-04V-A-S&currency=USD&specs=0)
| JST | 4-pin Connector | ASACHSACH28W152 | [Octopart](https://octopart.com/search?q=ASACHSACH28W152&currency=USD&specs=0)

As a silver lining to this issue - since pre-made cables are a bit harder to find, it's also less likely that someone can use a 3rd party cable with an incorrect pinout and destroy a PCB.

## Moving Forward with C3 - Introducing C4

We are also happy to announce that we are releasing a revision to the classic form factor unified daughterboard - the C4 revision.  
:size=600  

In addition to all the C3 features, C4 will also include:

- A swap to the Molex Pico-EZmate connector

To maintain backwards compatibility, cables with Pico-EZmate on one side and JST-SH with a 1:1 pinout will also be available.

The C4 Daughterboard is available [here](https://github.com/Unified-Daughterboard/UDB-C).

## Future Revisions
We already have a new revision of S1 and C4 in the works - but have chosen to release as-is because we think the new feature is not necessary for release, and so that designers can start designing around the S1.

The new revision of these boards will add USB 2.0 spec compliance to the daughterboards. The current C3, S1, and C4 are not technically spec compliant, but have been and will continue to function perfectly for our use cases. Additionally - most custom community keyboard PCBs also do not maintain USB 2.0 spec compliance.

By making the new revisions USB 2.0 spec compliant, we can also expand daughterboard use for additional use cases beyond typical keyboards.

Since this is a minor non-breaking change, the new revisions will be called S1.1 and C4.1, and we expect them to be released in the new few months.

## Special Thanks

While many keyboard and keyboard PCB designers contributed their ideas to this project, the lion's share of the actual PCB design and drawing work was done by three individuals:

- [Gondolindrim](https://github.com/Gondolindrim)
- [hineybush](https://hineybush.com/)
- [ai03](https://ai03.com/)

We'd like to thank them for their efforts.

## Other Credits

S1 Slimline:
- [GEON](https://geon.works/)
- [Sleepdealer](https://sleepdealer.xyz)
- [Xelus](https://xelus.me)
- [James (AKB)](https://alchemistkeyboards.com/)
- [kkatano](https://github.com/kkatano)
- [ToastyStoemp](https://vwolf.be)
- [Upas](https://cannonkeys.com)

C3 Unified:
- [Wilba](https://wilba.tech)
- Xondat
- [aeryxz](https://github.com/aeryxz)
- [Maximillian](https://github.com/Maximillian)

## Final Notes

- In our testing, we've found JST-ACH connectors and parts to be more or less cross compatible with Molex Pico-EZmate. We've chosen to refer to the connectors by their Molex nomenclature to help avoid confusion.
- Pico-EZmate / JST-ACH connectors do seem to be 1-2 cents more than JST-SH connectors. Nevertheless, we think it's worth swapping.
- At low volume, moving to 4 layers for the daughterboards from 2 layers only added a nominal cost. At high volume, the cost is negligible.
- We strongly considered swapping the pinout on the daughterboard to 4:1 - but decided against it given the existence of 1:1 Molex Pico-EZmate cables in the keyboard community already, and to maintain the 1:1 pinout of prior revisions.
- While the new Molex Pico-EZmate connectors are datasheet-rated for only 10 mating cycles, the previous JST-SH connectors were of unspecified rating but is likely inferred to be 10 as well from online discussions. We have stress-tested these connectors in real life, and found that the connection is perfectly fine after over 200 mating cycles, which should be far more than enough for any keyboard use. In addition, unlike the old JST-SH connectors which could slide out easily if they had become loose, the new Pico-EZmate connectors can be taped down vertically into the PCB for a simple, effective fix if the cable does become loose after excessive use. Due to this, we do not see the mating cycle restriction as an issue.

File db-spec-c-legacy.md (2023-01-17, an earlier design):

# Legacy C series (C3 and older) 

## Overview

The legacy C3 daughterboard is a classic square form-factor daughterboard, with its roots in the C1 which was designed to be compatible with Wilba's keyboards.  
This is the last revision uDB which uses the JST-SH series connector - the [successor C4 and newer](db-spec-c.md) uses the Pico-EZmate connector instead.  

!>This legacy C series design is obsolete, only being documented for the sake of maintaining old keyboards which cannot be upgraded to C4 for one reason or another.  
For new projects, please use either the [C series](db-spec-c.md) or [S series](db-spec-s.md) daughterboards instead.
  
The daughterboard features the following:  

* ESD (Electrostatic Discharge) protection on the data lines of the USB connector through a specialized chip;
* Overcurrent protection through a PTC fuse;
* Overvoltage protection through a bidirectional TVS diode;
* Shielding noise decoupling capabilities through a ferrite bead;
* Single-path grounding of the metallic chassis to which the daughterboard is attached.
* Same form factor as the C legacy series, allowing for daughterboard upgrades

## Specification

* Overall size: 18 x 16.5 mm
* Screw holes: 14 x 12.5 mm apart.  
* Corner radius: 2 mm
* Hardware: M2 screws
* Connector: JST-SH (JST SM04B-SRSS-TB(LF)(SN))
* PCB layers: 2

## Resources

[GitHub](https://github.com/Unified-Daughterboard/UDB-C-Legacy ':ignore')  
[3D model](/_media/uDB-C3-3D-model.STEP ':ignore')  
[Example implementation](/_media/uDB-C3-implementation-example.step ':ignore')  
[Production data](https://github.com/Unified-Daughterboard/UDB-C-Legacy/tree/master/Production/C3 ':ignore')

## Images and Diagrams

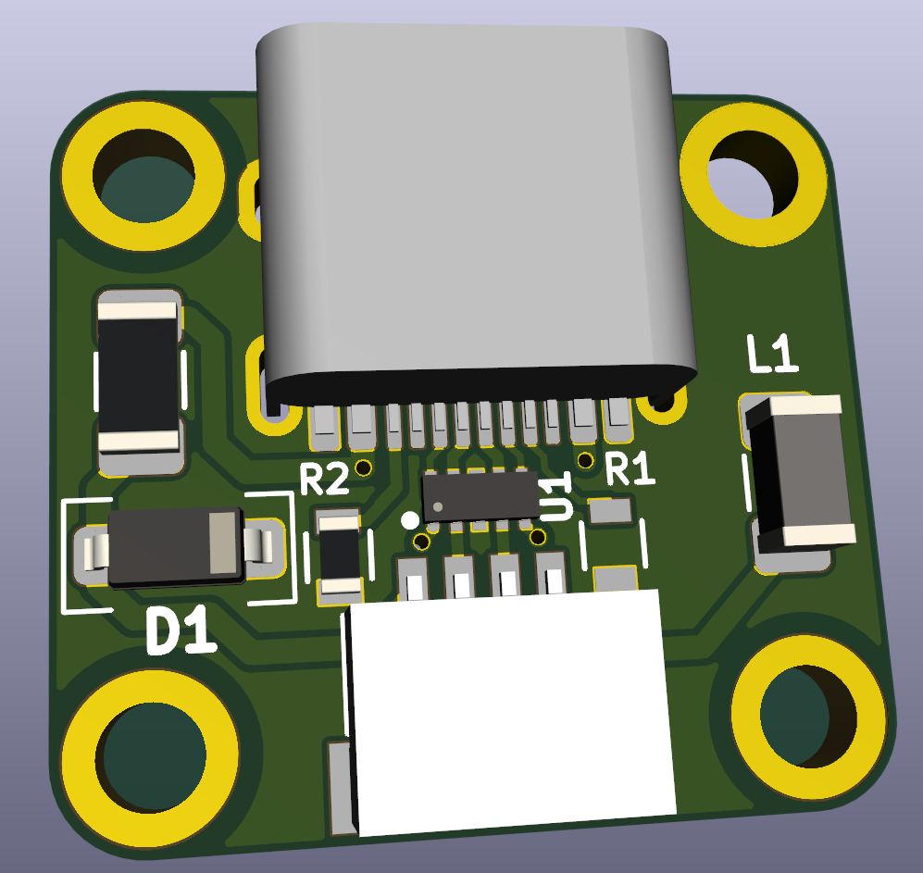
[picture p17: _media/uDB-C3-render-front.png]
Render front :size=600
  
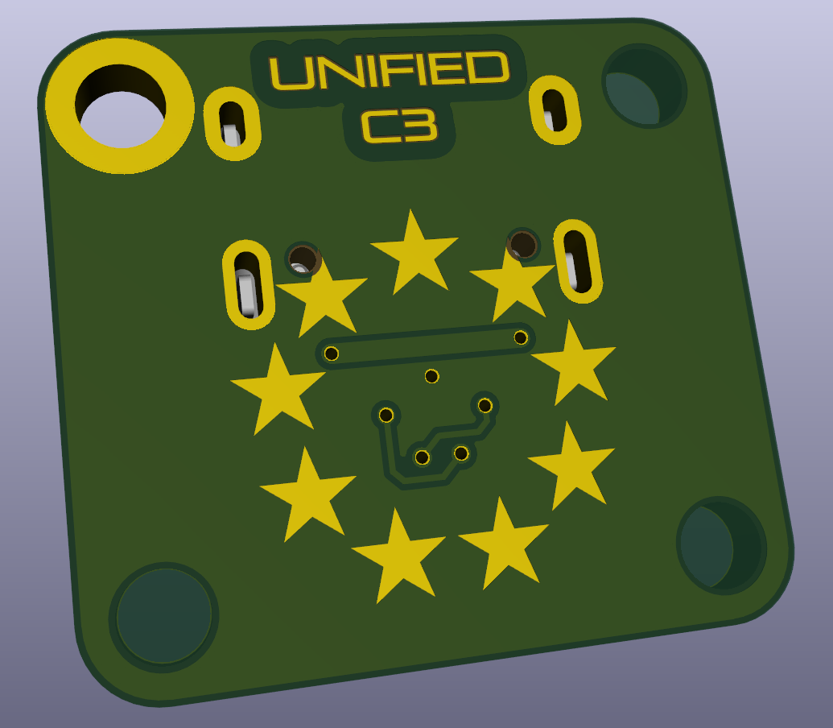
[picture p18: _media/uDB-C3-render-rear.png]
Render rear :size=600
  
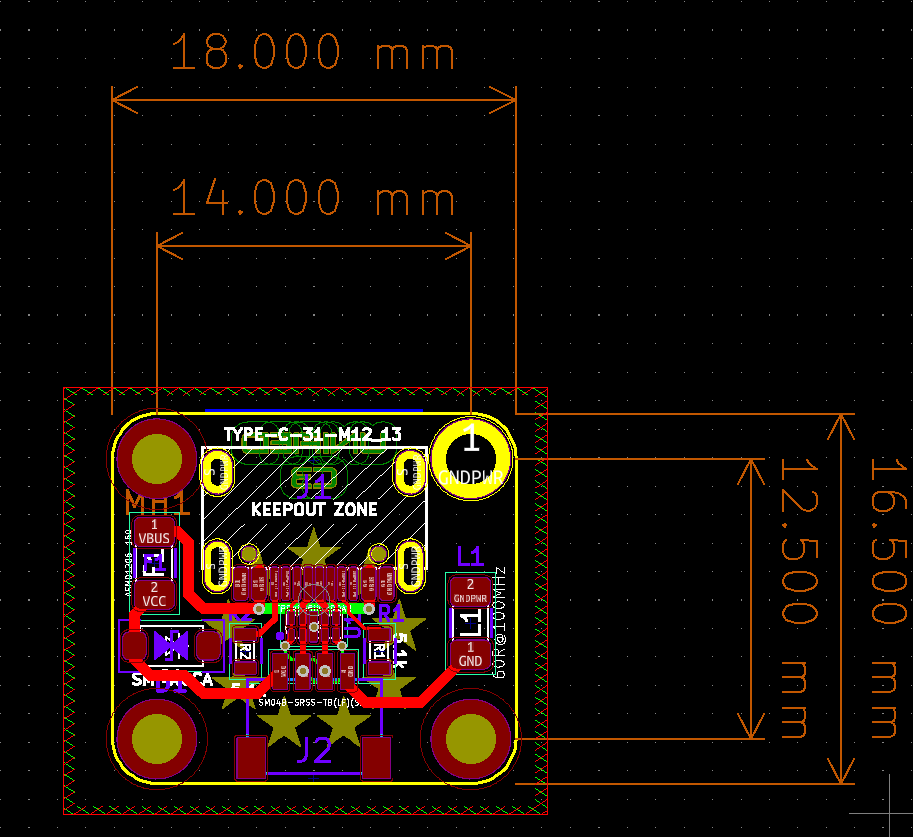
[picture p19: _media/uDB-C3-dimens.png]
C Legacy :size=600


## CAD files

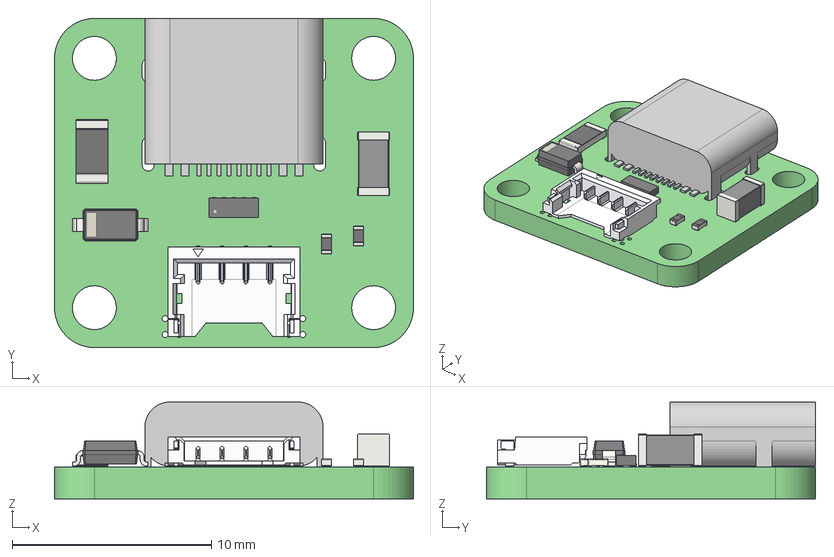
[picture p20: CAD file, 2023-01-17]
_media/uDB-C4-3D-model.step
18.0 x 16.5 x 4.86 mm
_autosave-UDB PCB

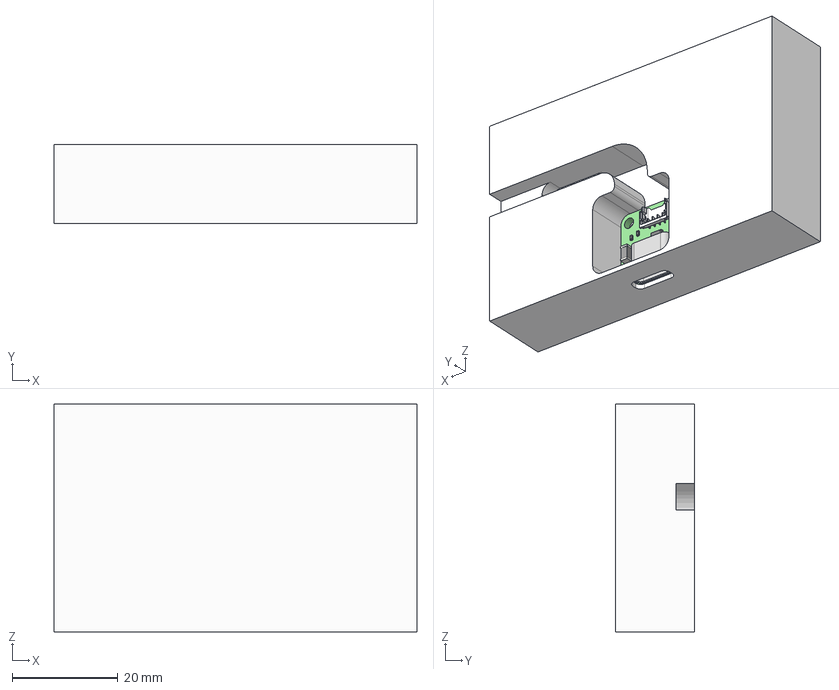
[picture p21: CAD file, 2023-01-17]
_media/uDB-C4-implementation-example.step
68.5 x 15.0 x 43.0 mm
_autosave-UDB PCB

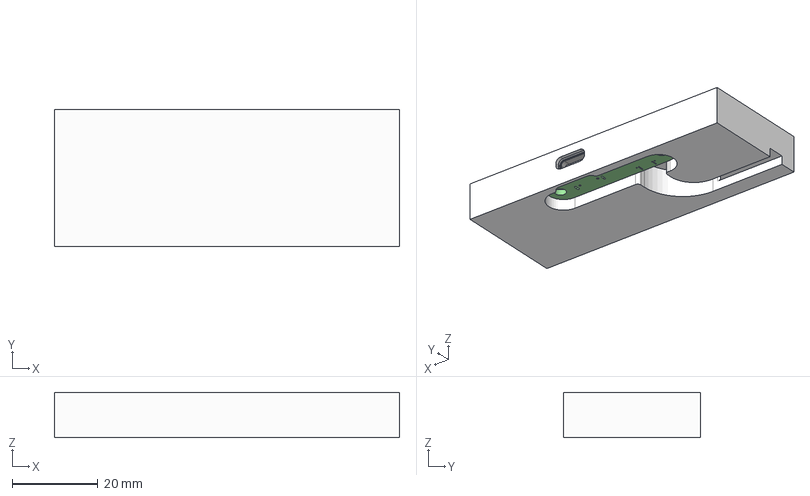
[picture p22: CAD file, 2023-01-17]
_media/uDB-S1-implementation-example-reverse.step
80.5 x 32.0 x 10.5 mm
udb-s PCB
Example Shell

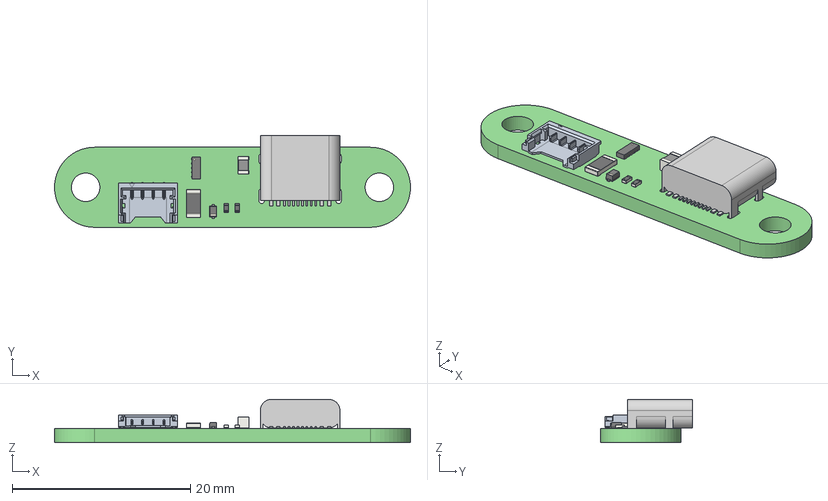
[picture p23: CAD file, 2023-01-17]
_media/uDB-S1-3D-model.STEP
40.0 x 10.3 x 4.87 mm
udb-s PCB

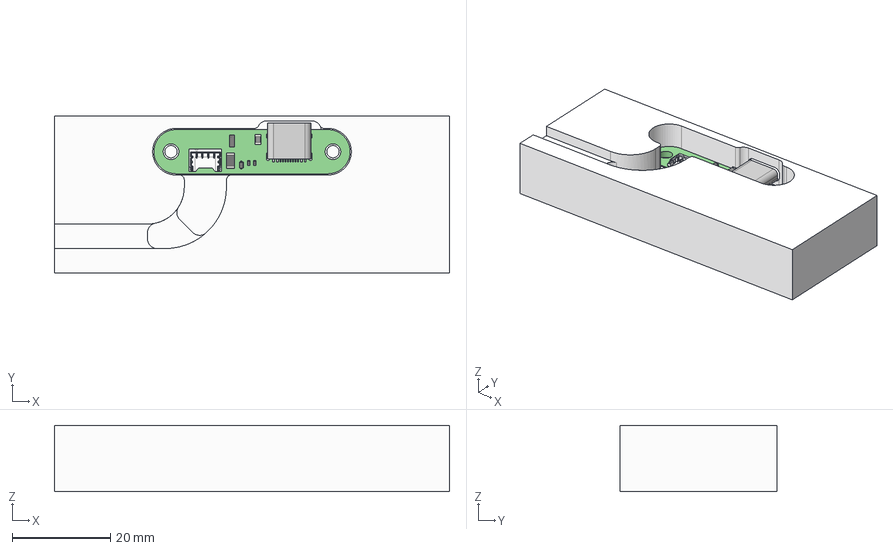
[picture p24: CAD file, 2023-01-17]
_media/uDB-S1-implementation-example.step
80.5 x 32.0 x 13.5 mm
udb-s PCB
Example Shell

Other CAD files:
_media/uDB-C3-3D-model.step
_media/uDB-C3-implementation-example.step

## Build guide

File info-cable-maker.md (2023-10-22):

# Notices for Custom USB Cable Makers

We've compiled a list of important notices for USB cable makers.

## Proper Wiring and ESD Handling

While the Unified Daughterboard has many layers of ESD protection in place, its effect is greatly diminished or potentially nonexistent without a proper USB-spec cable.  

!>There have been numerous reports of people destroying their keyboards with static shocks when using custom cables with a missing or incorrectly wired shield.  
  
**Offical USB foundation specifications dictate that the cable assemblies need to have the shield and ground tied at both ends of the cable for USB 2.0, USB 3.0 and USB 3.1**.  
To protect the keyboards of your users, when making USB cables, please make sure that your cable follows proper USB spec [outlined in the USB foundation document](https://www.usb.org/sites/default/files/USB%20Type-C%20Spec%20R2.0%20-%20August%202019.pdf) (sections 3.4.1 to 3.4.2, sections 3.5.1 to 3.5.2).  
  
While all sections of the document are important, please note the following in particular:  
  
* A robust, continuous outer shield exists **separately from the ground conductor**.  
* The **shield is wired properly to the shell of the connector at both ends**.  
* The **shield is connected to ground** as per the spec **within the connector at both ends**.  

An excerpt of the USB spec document for USB 2.0 A-to-C cables is attached below.  
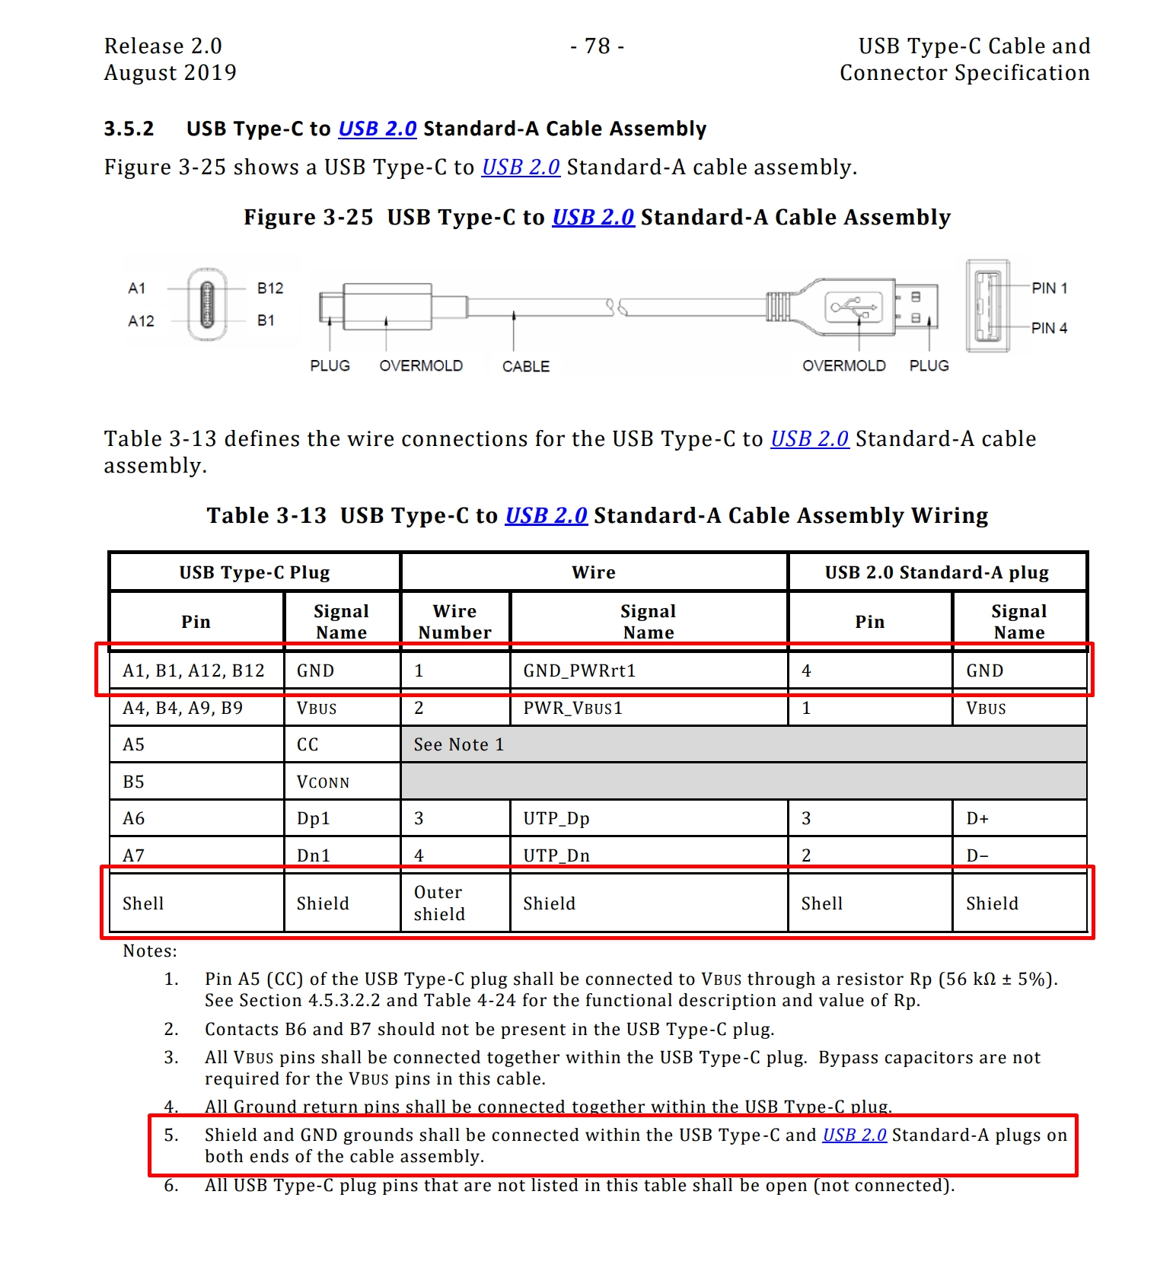
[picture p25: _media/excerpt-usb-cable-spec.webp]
USB Spec Excerpt :size=600


## Proper Pinout
  
The Unified Daughterboard cannot be used with cables with incorrectly wired power/data conductors, and may fail catastrophically under such cases.  
Please ensure that the cables are properly wired, and that the pinout cannot change due to shorts within the cable or intermediate connectors.

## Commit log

2023-01-17 Build site
    [example-impl-C3.step, uDB-C3-3D-model.step, uDB-S1-3D-model.STEP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]
2023-01-17 Add C4 page
    [uDB-C3-implementation-example.step, uDB-C4-3D-model.step, uDB-C4-implementation-example.step]
2023-03-29 Add notices for USB cables
